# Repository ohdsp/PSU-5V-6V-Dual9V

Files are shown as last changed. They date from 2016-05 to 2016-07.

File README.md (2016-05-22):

# [Open Hardware DSP Platform](http://www.ohdsp.org)
## Multi output power supply for OHDSP
### Revision 1.1
###### PSU-5V-6V-Dual9V (KiCad 4.0.2-stable)
---
# README
### Disclaimer
Copyright Paul Janicki 2016

Licensed under the TAPR Open Hardware License (www.tapr.org/OHL)

This documentation is distributed WITHOUT ANY EXPRESS OR IMPLIED WARRANTY, INCLUDING OF MERCHANTABILITY, SATISFACTORY QUALITY AND FITNESS FOR A PARTICULAR PURPOSE.

### What is this repository? ###

**Quick summary**

This is a power supply for use with OHDSP boards.

This power supply requires a single 9Vac input (around 500mA should be sufficient for simple systems). 

This power supply outputs one 5V, one 5V or 6V, and +/-9V. Be warned that each of the 5V and 6V rail should be able to deliver higher currents (up to 1A) without issue, but this will overload the input if you are not careful.

This repository contains the KiCad design files, manufacturing Gerber/drill files, and PDF/drawing files for this board.

### How do I get set up? ###

**Summary of set up**

1. Set your self up a directory on a local disk, something simple will make life easier (eg C:\Electronics on Windows as used here), but anywhere will do just fine.
2. Download the Kicad-Libs from [https://github.com/ohdsp/KiCad-Libs](https://github.com/ohdsp/KiCad-Libs) and place in C:\Electronics\Kicad-Libs (or your chosen folder)  
3. Create a OHDSP subdirectory in C:\Electronics (so C:\Electronics\OHDSP)
3. Download this project to C:\Electronics\OHDSP\PSU-5V-6V-Dual9V
4. Fire up Kicad
5. Open the main project file C:\Electronics\OHDSP\PSU-5V-6V-Dual9V\Schematics\PSU-5V-6V-Dual9V.pro
6. (Optional) Setup Pcbnew component library as below.
7. Do as you wish with the project, just keep it under TAPR Open Hardware License

Make sure your git setup doesn't exclude files used in the project (like .LIB files) or things may go wrong down the line.

**KiCad Library Configuration**

Note that you need to setup a Pcbnew library, but the eeschema libraries should work without any changes if you followed the instructions above.

To setup Pcbnew libraries:

In Pcbnew go to Preferences -> Footprint Libraries Manager. Under Global Libraries tab in the top list check if there is a nickname "MyKiCadLibs-Footprints" (usually at the end of the list). If there is but it points to the wrong place then change the Library Path to point to MyKiCadLibs-Footprints (eg C:\Electronics\KiCad-Libs\MyKiCadLibs-Footprints.pretty) folder for your setup. If this is missing you can use "Append with Wizard", choose "Files on my computer", click next, browse to library location (eg C:\Electronics\KiCad-Libs\MyKiCadLibs-Footprints.pretty) and select the folder MyKiCadLibs-Footprints.pretty, click next, check the Status column states OK and the Format is KiCad (if not re-download the library) and click next, then select "To global library configuration..." and click Finish.

To setup eeschema component libraries:
Either from KiCad project window go to Tools -> Run Library Editor OR under eeschema, go to Tools -> Library Editor. Then Preferences -> Component Libraries.

The top section "Component Library Files" should ideally contain only two libraries, the "power" library that ships with KiCad and "MyKiCadLibs-Lib" available from above. To setup MyKiCadLibs-Lib as a relative path under the "User defined search path" click add. Browse to the location of KiCad-Libs you download above (eg C:\Electronics\KiCad-Libs) and click "Select Folder". Say yes to add a relative path. Under component library files click add, browse to the KiCad-libs again (eg C:\Electronics\KiCad-Libs), select file "MyKiCadLibs-Lib.lib" and click open. MyKiCadLibs-lib should appear in the component library list with no path as it will be using the user defined search path set in the box below.

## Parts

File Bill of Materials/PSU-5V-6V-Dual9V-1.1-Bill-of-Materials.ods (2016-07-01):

PSU-5V-6V-Dual9V Bill of Materials – Revision 1.1
20 May 2016
Reference | Quantity | Footprint | Value | Description | Voltage | Type | Tolerance | Size | Current | Power
C115 C116 | 2 | SMD-0805 | 100p | 'Ceramic capacitor | '50V | 'C0G | '5% | '0805 | ' | '
C105 C106 C117 C118 | 4 | CAP-TH-D18mmP7.5mm | 2200u | 'Aluminium electrolytic | '25V | ' | ' | '7.5mm Pitch, 18mm Diameter | ' | '
C103 C104 C109 C110 C119 C120 C129 C130 C133 C134 C141 C142 C145 C146 | 14 | SMD-0805 | 22u | 'Ceramic capacitor | '25V | 'X5R | '20% | '0805 | ' | '
C107 C108 C111 C112 C121 C122 C131 C132 C135 C136 C139 C140 C143 C144 | 14 | SMD-0805 | 100n | 'Ceramic capacitor | '50V | 'X7R | '10% | '0805 | ' | '
C113 C114 C123 C124 C125 C126 | 6 | SMD-0805 | 10n | 'Ceramic capacitor | '50V | 'X7R | '10% | '0805 | ' | '
C101 C102 C127 C128 C137 C138 C147 C148 C149 C150 | 10 | CAP-TH-D8mmP3.5mm | 220u | 'Aluminium electrolytic low impedance capacitor - eg Panasonic FC or FR parts | '25V | ' | ' | '3.5mm Pitch, 8mm Diameter | ' | '
D101 D102 | 2 | DIODE-SMC | ES3D | 'ES3D 3A 200V Fast Rectifier | ' | ' | ' | ' | ' | '
D103 D104 | 2 | DIODE-SMA | B240A | 'B240A 2A 40V Schottky Rectifier - SMA (DO-214AC) | ' | ' | ' | ' | ' | '
D105 D106 D107 D108 | 4 | DIODE-SOD-123 | SS14L | 'SS14L 1A 40V Schottky rectifier - Sub-SMA (SOD-123) | ' | ' | ' | ' | ' | '
D109 | 1 | SMD-1206 | Green LED 1206 | 'Green LED - SMD - Vf 1.8V to 2.2V | ' | ' | ' | '1206 | ' | '
FID1 FID2 FID3 FID4 | 4 | FID-1MM-3MM | MNT_HOLE | 'Fiducial | ' | ' | ' | ' | ' | '
L101 L102 | 2 | SMD-0805 | 600R@100MHz | 'Ferrite bead, current rating 2A or higher, 600R@100MHz | ' | ' | ' | '0805 | '=>2A | '
L103 L104 | 2 | IND-TYS5040-HS | TYS50406R8M-10 | 'Laird Technologies TYS5040 6.8uH Inductor - 2.5A Irms, 2.9A Isat, 0.043ohm, 21MHz | ' | ' | ' | ' | '2.5A | '
MNT1 MNT2 MNT3 MNT4 | 4 | MNT_HOLE_3.2mm | MNT_HOLE | 'Mounting hole | ' | ' | ' | ' | ' | '
P103 P106 P107 P108 P109 P110 P111 P112 P113 P114 P115 P116 P117 | 13 | CONN-2WAY-2.54mm-3.81mm-SPACING | CONN_2x1 | '2 way screw terminal, any 2.54mm to 3.81mm pitch part | ' | ' | ' | ' | ' | '
R101 R103 | 2 | SMD-0805 | 475k | 'Thick or thin film resistor | ' | ' | '1% | '0805 | ' | '100mW
R102 R104 | 2 | SMD-0805 | 100k | 'Thick or thin film resistor | ' | ' | '1% | '0805 | ' | '100mW
R105 R106 | 2 | SMD-0805 | 47 | 'Thick or thin film resistor | ' | ' | '1% | '0805 | ' | '100mW
R107 | 1 | SMD-0805 | 53k6 | 'Thick or thin film resistor | ' | ' | '1% | '0805 | ' | '100mW
R108 R111 | 2 | SMD-0805 | 10k | 'Thick or thin film resistor | ' | ' | '1% | '0805 | ' | '100mW
R109 | 1 | SMD-0805 | 470 | 'Thick or thin film resistor | ' | ' | '1% | '0805 | ' | '100mW
R110 | 1 | SMD-0805 | 66k5 | 'Thick or thin film resistor | ' | ' | '1% | '0805 | ' | '100mW
R113 R114 | 2 | SMD-0805 | 750 | 'Thick or thin film resistor - 250mW | ' | ' | '1% | '0805 | ' | '250mW
R115 R116 | 2 | SMD-0805 | 120 | 'Thick or thin film resistor - 250mW | ' | ' | '1% | '0805 | ' | '250mW
U101 U102 | 2 | IC-SOT23-6 | ADP2301AUJZ | '1.2 A, 20 V, 700 kHz/1.4 MHz, Nonsynchronous Step-Down Regulator | ' | ' | ' | ' | ' | '
U103 | 1 | IC-TO220-HS-SW25-2G | LM317 | 'LM317 TO220 3-Terminal Adjustable Positive Regulator | ' | ' | ' | ' | ' | '
U104 | 1 | IC-TO220-HS-SW25-2G | LM337 | 'LM337 TO220 3-Terminal Adjustable Negative Regulator | ' | ' | ' | ' | ' | '

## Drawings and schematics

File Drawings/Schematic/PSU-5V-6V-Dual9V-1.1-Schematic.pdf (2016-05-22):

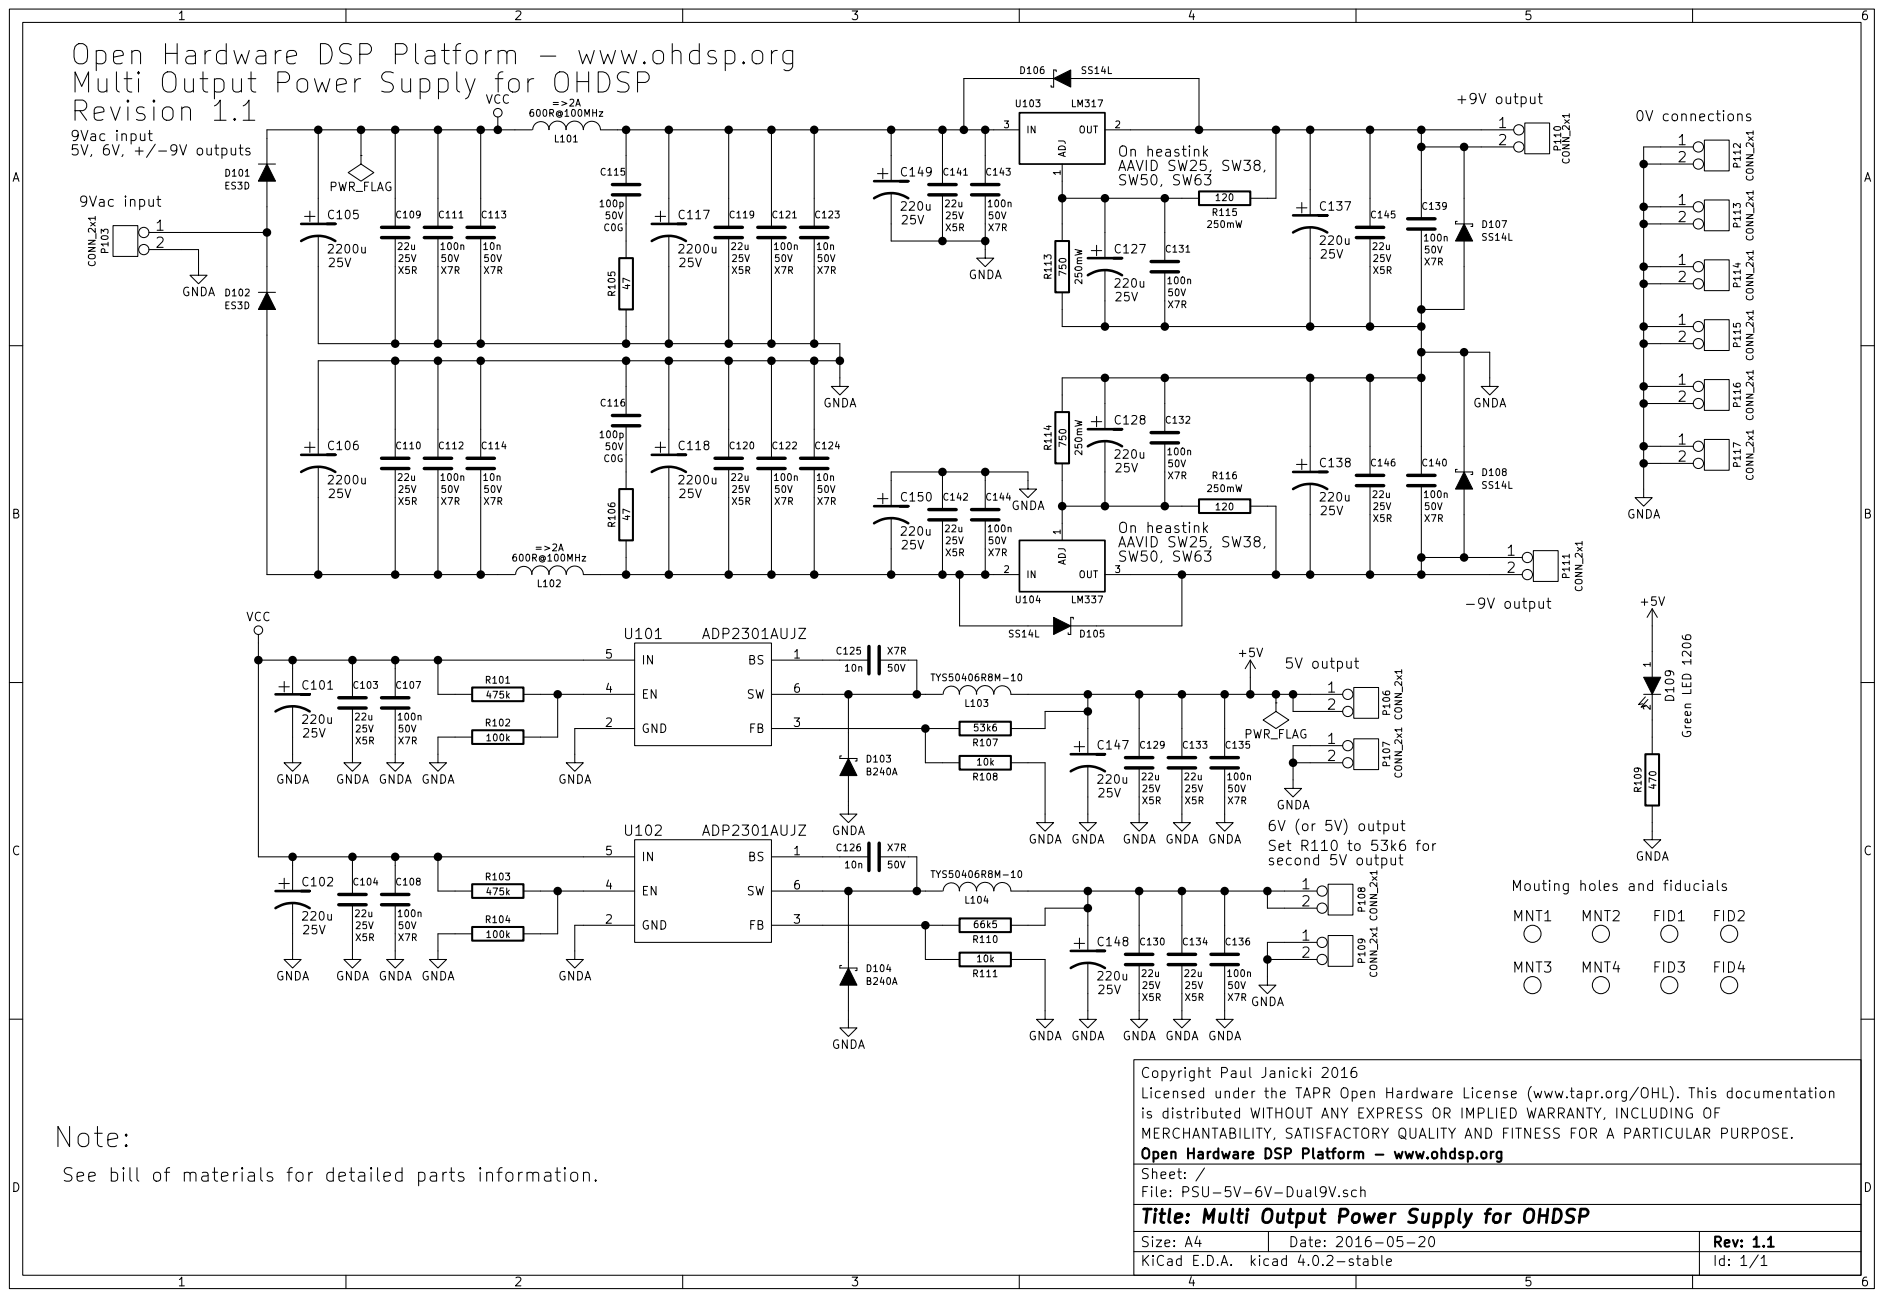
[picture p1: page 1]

Open Hardware DSP Platform - www.ohdsp.org
Multi Output Power Supply for OHDSP
Revision 1.1

Copyright Paul Janicki 2016
Licensed under the TAPR Open Hardware License (www.tapr.org/OHL). This documentation
is distributed WITHOUT ANY EXPRESS OR IMPLIED WARRANTY, INCLUDING OF
MERCHANTABILITY, SATISFACTORY QUALITY AND FITNESS FOR A PARTICULAR PURPOSE.
File: PSU-5V-6V-Dual9V.sch Sheet: / Open Hardware DSP Platform - www.ohdsp.org

Id: 1/1 Title: Multi Output Power Supply for OHDSP

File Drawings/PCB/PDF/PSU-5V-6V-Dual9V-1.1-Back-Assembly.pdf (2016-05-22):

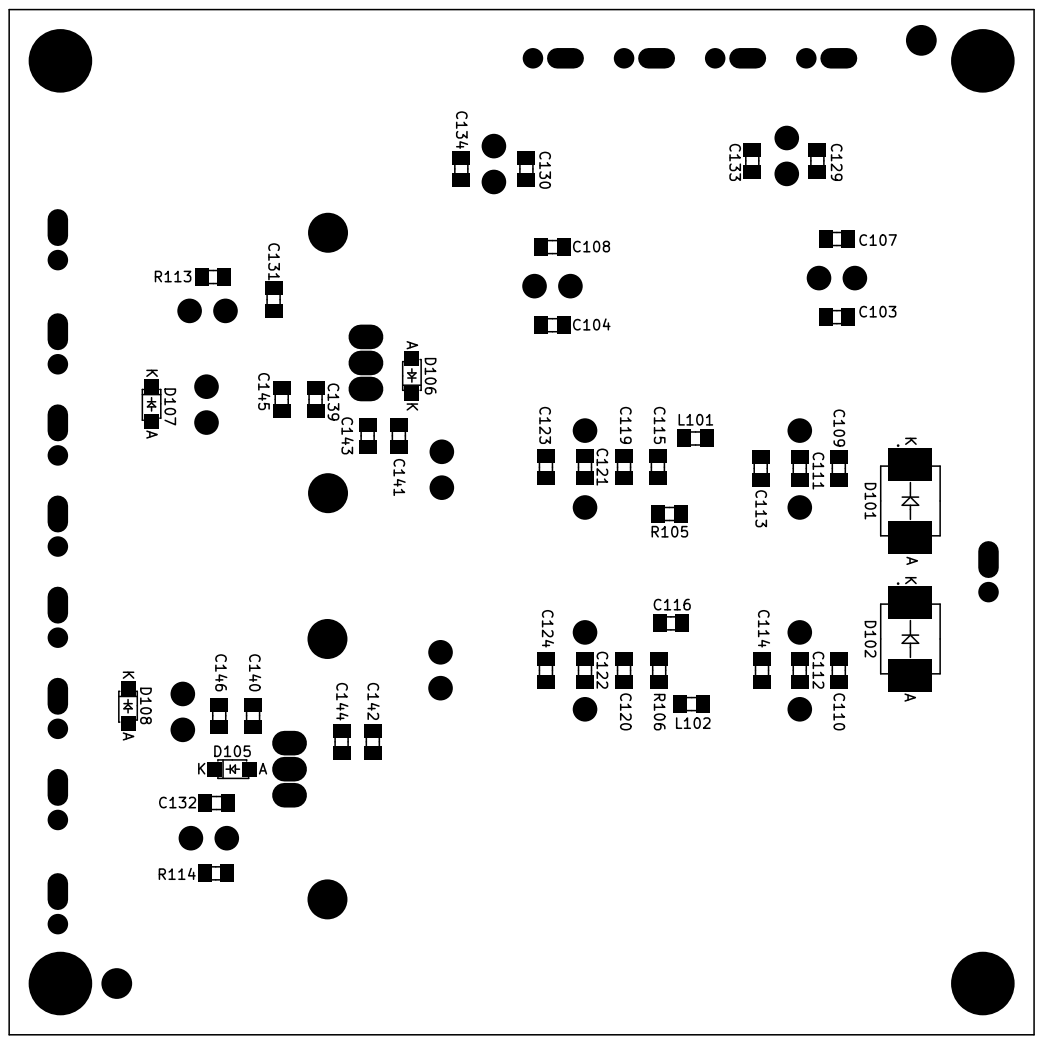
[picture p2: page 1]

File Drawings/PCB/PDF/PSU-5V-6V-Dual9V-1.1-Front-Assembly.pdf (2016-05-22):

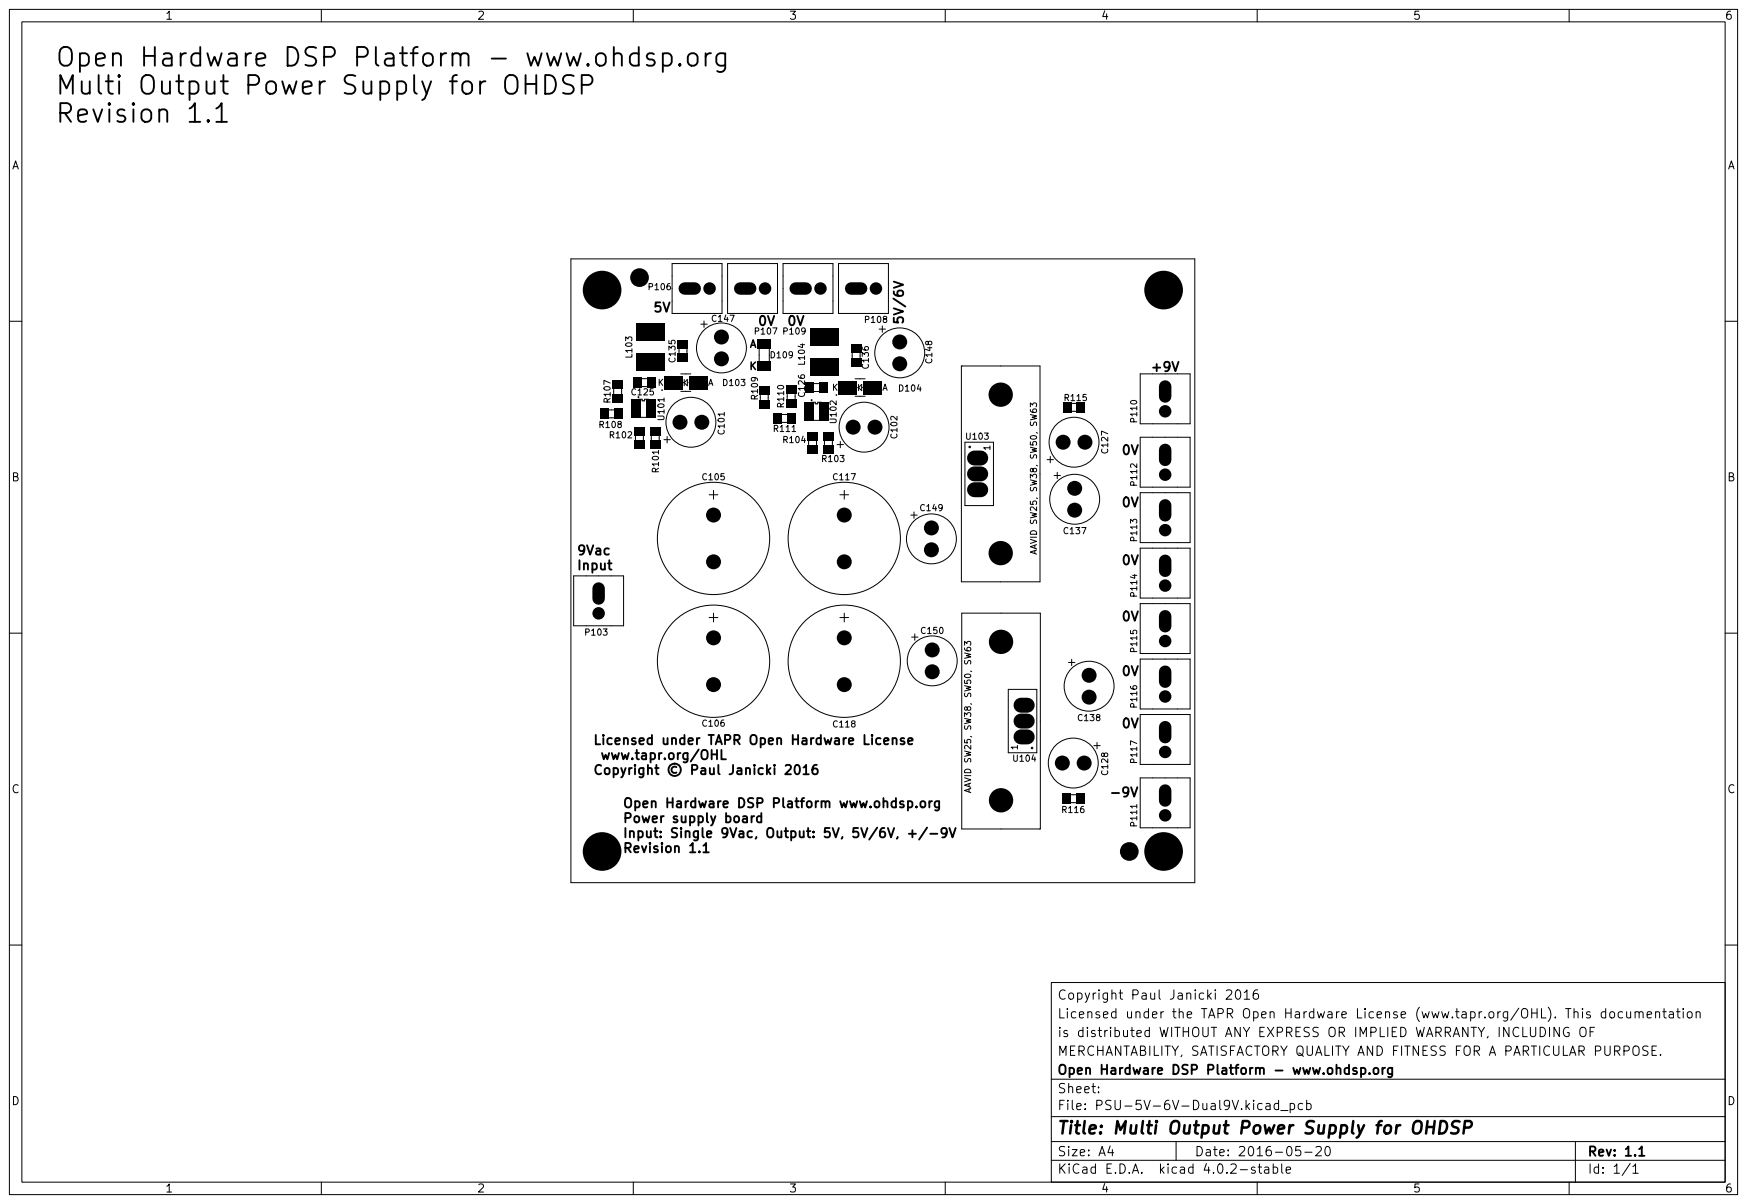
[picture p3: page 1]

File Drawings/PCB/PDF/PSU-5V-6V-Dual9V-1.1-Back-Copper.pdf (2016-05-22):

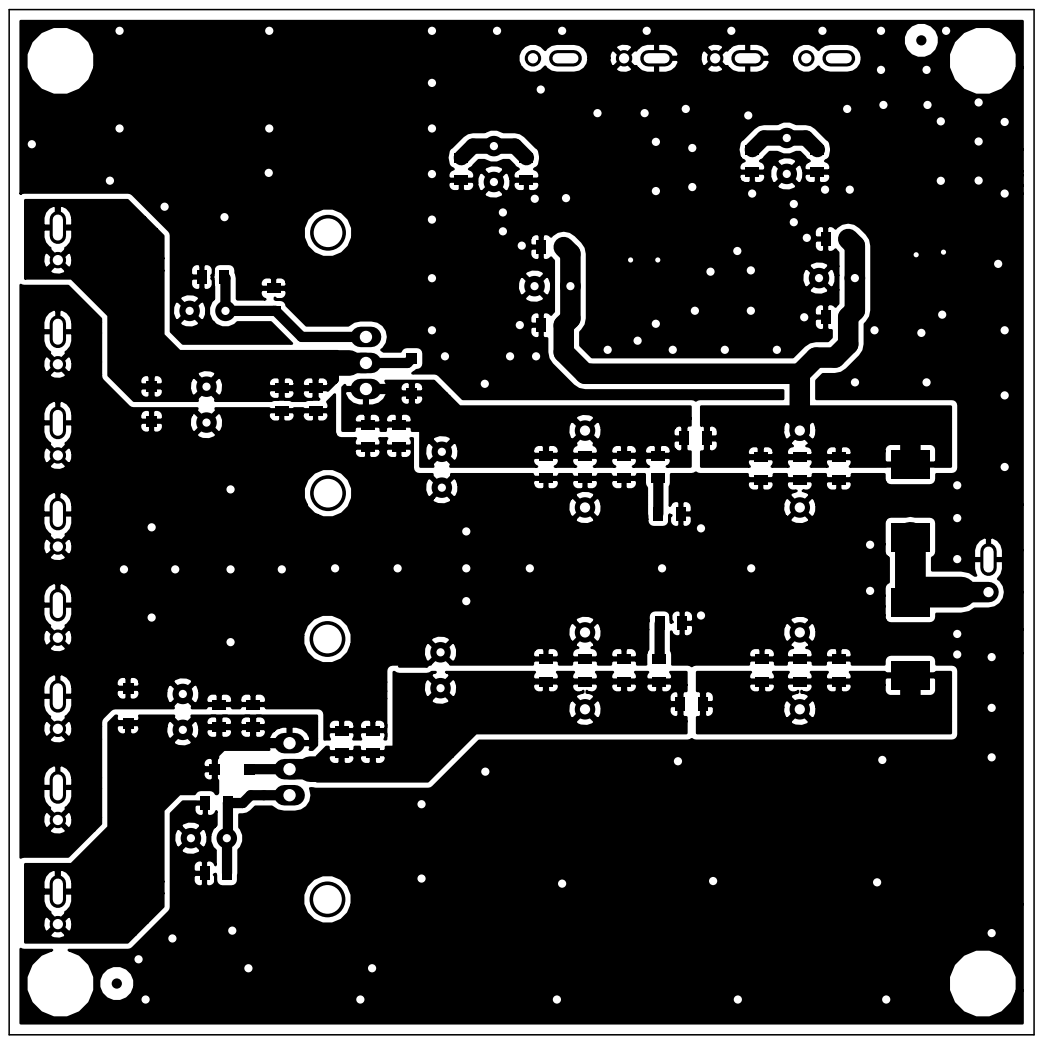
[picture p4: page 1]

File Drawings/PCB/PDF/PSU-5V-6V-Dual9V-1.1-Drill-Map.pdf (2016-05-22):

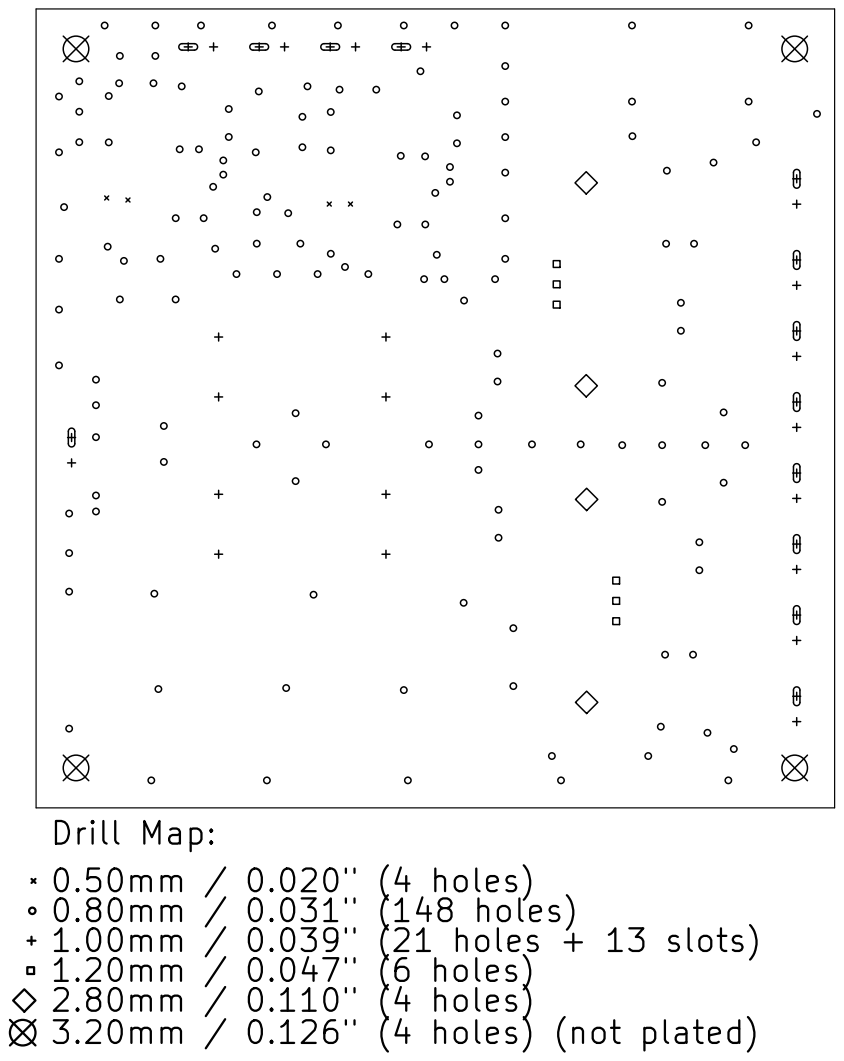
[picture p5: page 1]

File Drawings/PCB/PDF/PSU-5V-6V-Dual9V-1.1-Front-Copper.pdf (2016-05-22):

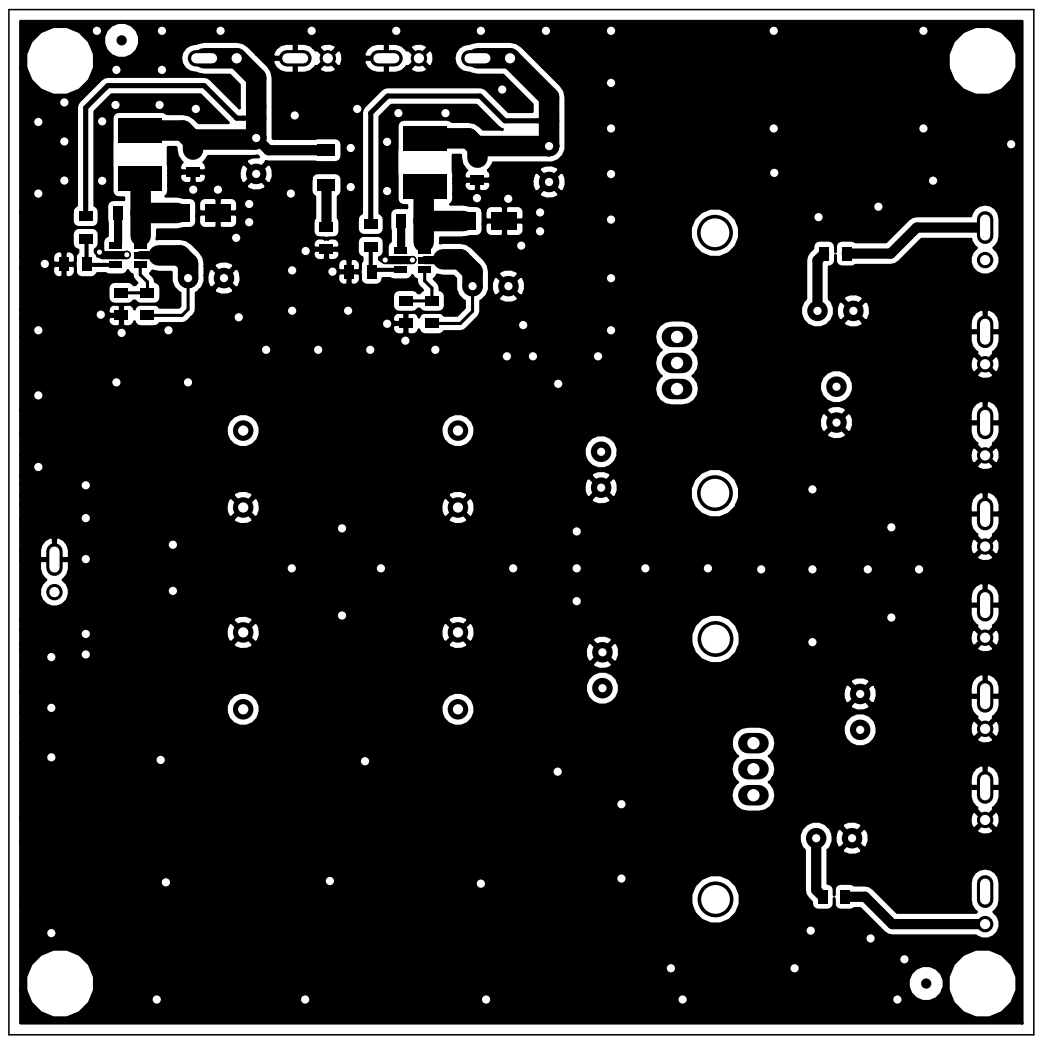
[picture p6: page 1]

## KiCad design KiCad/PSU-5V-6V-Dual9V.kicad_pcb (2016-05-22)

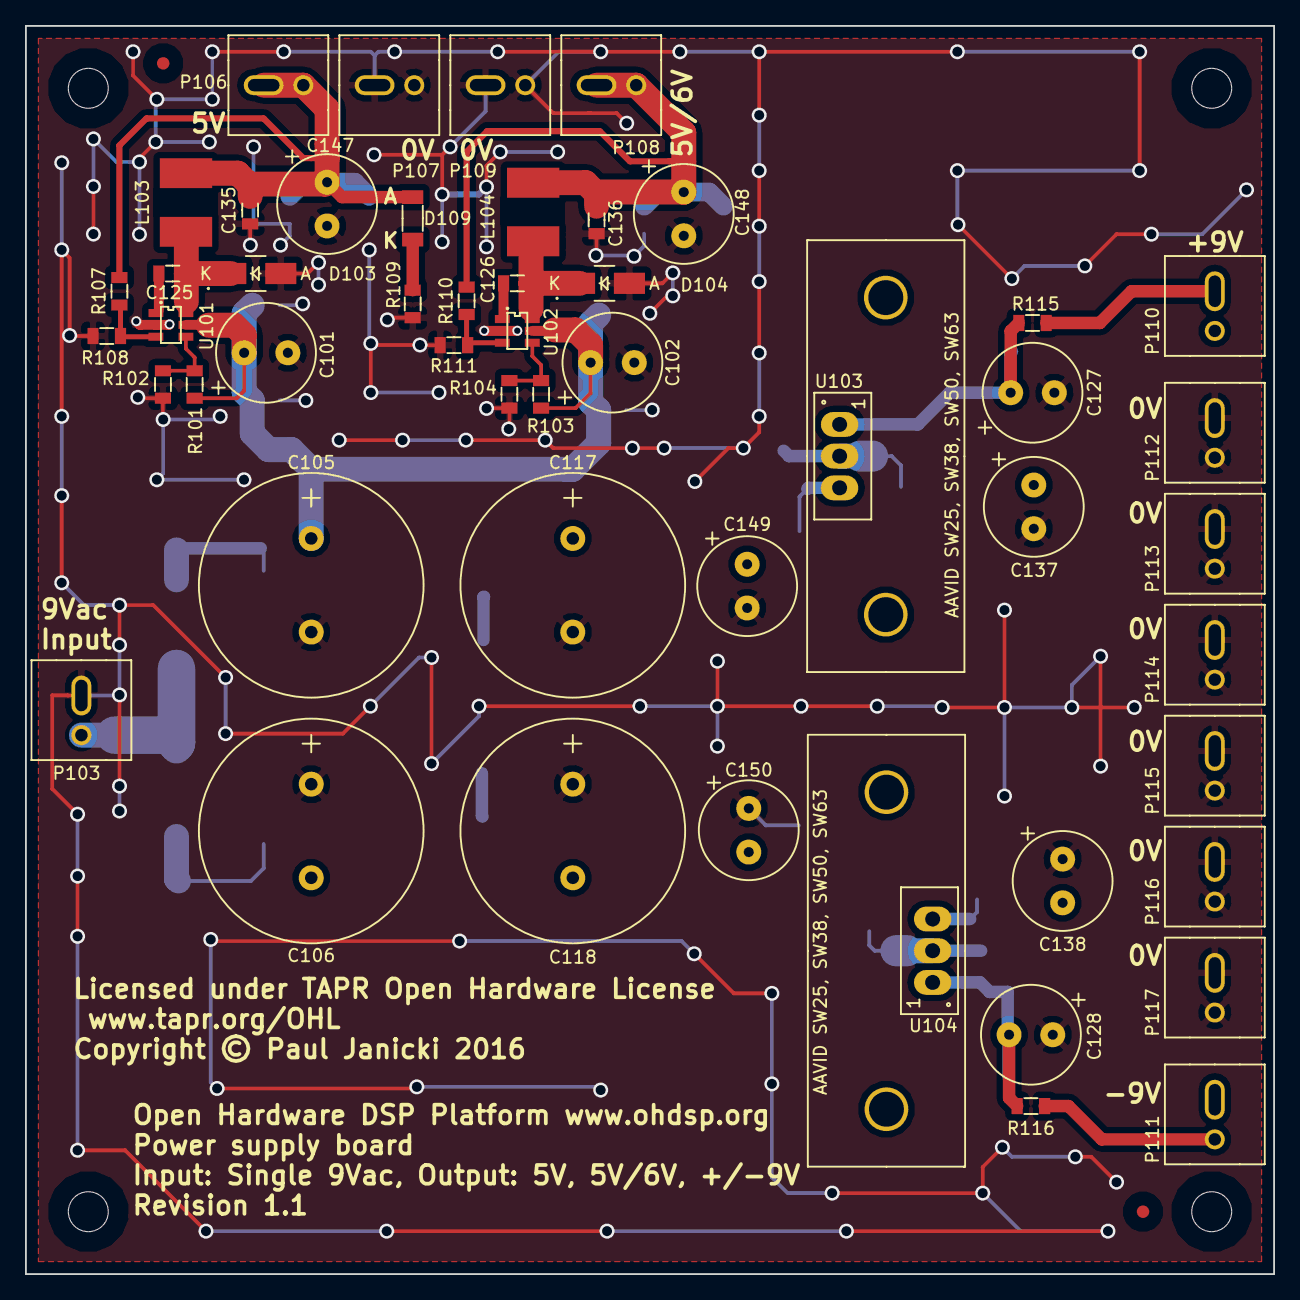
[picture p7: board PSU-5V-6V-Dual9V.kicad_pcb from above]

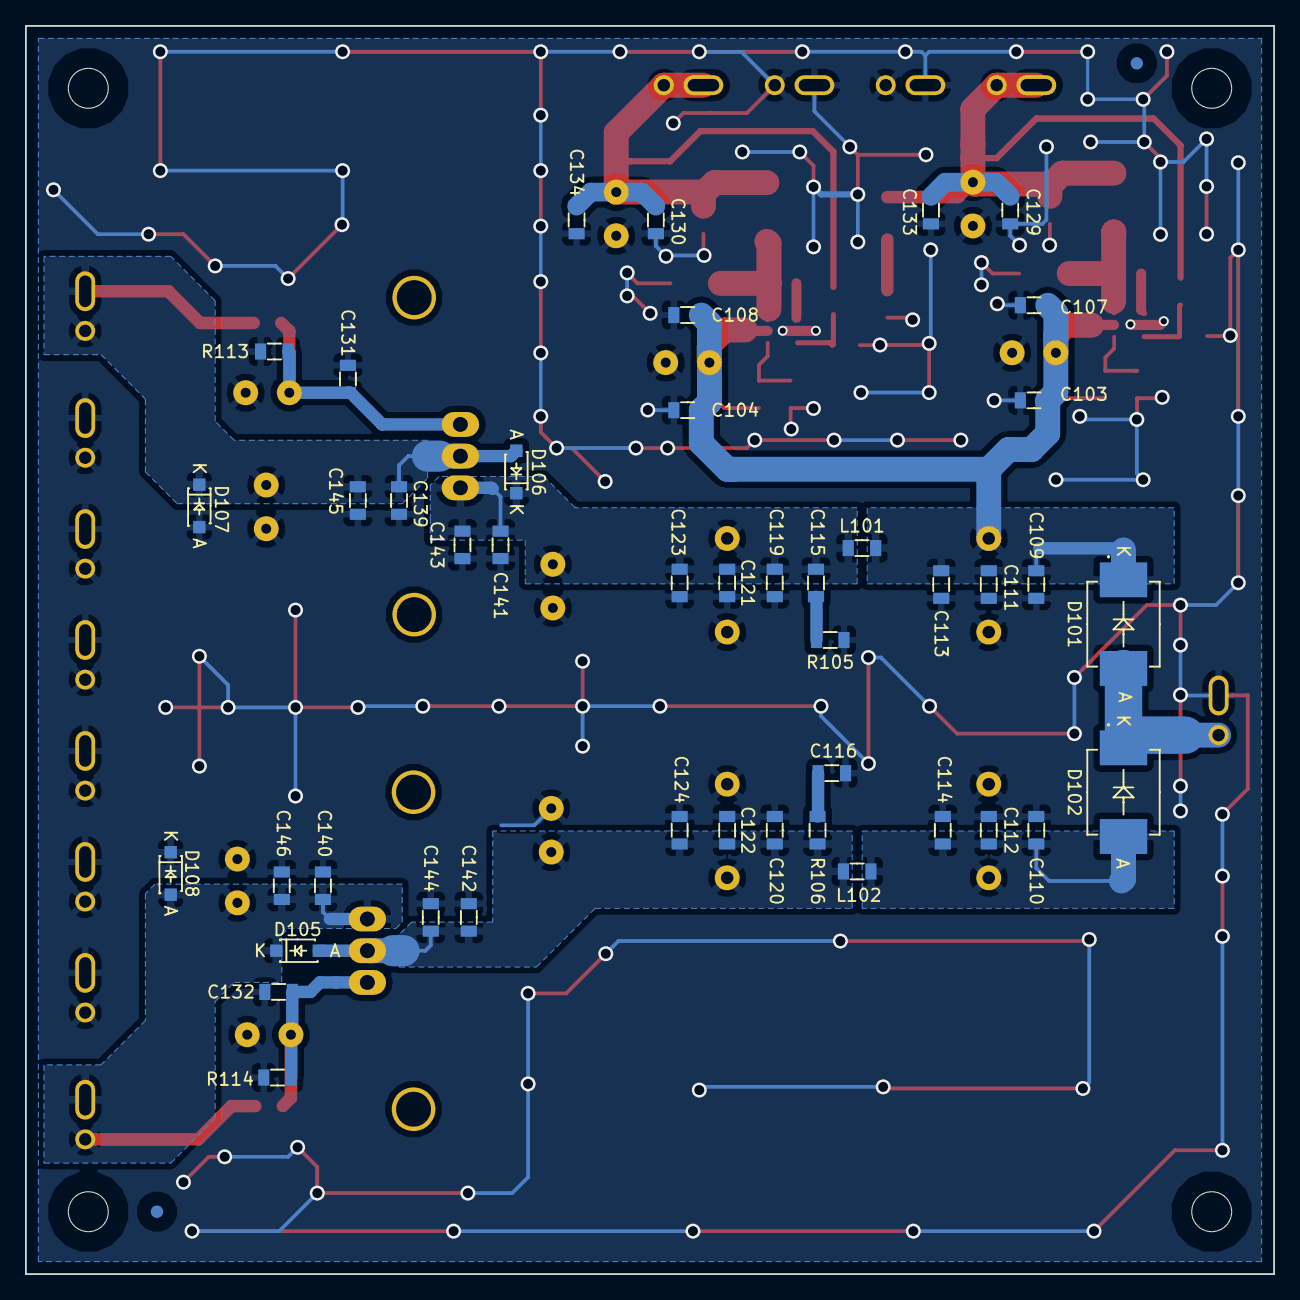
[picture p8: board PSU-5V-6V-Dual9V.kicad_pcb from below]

Board: 2 copper layers, 100.0 x 100.0 mm, 103 parts (46 on the bottom side), 23 nets.

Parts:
C101, C102, C127, C128, C137, C138, C147, C148, C149, C150: 220u; CAP-TH-D8mmP3.5mm
C103, C104, C109, C110, C119, C120, C129, C130, C133, C134, C141, C142, C145, C146: 22u; SMD-0805
C105, C106, C117, C118: 2200u; CAP-TH-D18mmP7.5mm
C107, C108, C111, C112, C121, C122, C131, C132, C135, C136, C139, C140, C143, C144: 100n; SMD-0805
C113, C114, C123, C124, C125, C126: 10n; SMD-0805
C115, C116: 100p; SMD-0805
D101, D102: ES3D; DIODE-SMC
D103, D104: B240A; DIODE-SMA
D105, D106, D107, D108: SS14L; DIODE-SOD-123
D109: Green LED 1206; SMD-1206
FID1, FID2, FID3, FID4: MNT_HOLE; FID-1MM-3MM
L101, L102: 600R@100MHz; SMD-0805
L103, L104: TYS50406R8M-10; IND-TYS5040-HS
MNT1, MNT2, MNT3, MNT4: MNT_HOLE; MNT_HOLE_3.2mm
P103, P106, P107, P108, P109, P110, P111, P112, P113, P114, P115, P116, P117: CONN_2x1; CONN-2WAY-2.54mm-3.81mm-SPACING
R101, R103: 475k; SMD-0805
R102, R104: 100k; SMD-0805
R105, R106: 47; SMD-0805
R107: 53k6; SMD-0805
R108, R111: 10k; SMD-0805
R109: 470; SMD-0805
R110: 66k5; SMD-0805
R113, R114: 750; SMD-0805
R115, R116: 120; SMD-0805
U101, U102: ADP2301AUJZ; IC-SOT23-6
U103: LM317; IC-TO220-HS-SW25-2G
U104: LM337; IC-TO220-HS-SW25-2G

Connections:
+5V: C129.1, C133.1, C135.1, C147.1, D109.1, L103.2, P106.1, P106.2, R107.1
GNDA: C101.2, C102.2, C103.2, C104.2, C105.2, C106.1, C107.2, C108.2, C109.2, C110.1, C111.2, C112.1, C113.2, C114.1, C116.1, C117.2, C118.1, C119.2, C120.1, C121.2, C122.1, C123.2, C124.1, C127.2, C128.1, C129.2, C130.2, C131.2, C132.1, C133.2, C134.2, C135.2, C136.2, C137.2, C138.1, C139.2, C140.1, C141.2, C142.1, C143.2, C144.1, C145.2, C146.1, C147.2, C148.2, C149.2, C150.1, D103.1, D104.1, D107.1, D108.2, P103.2, P107.1, P107.2, P109.1, P109.2, P112.1, P112.2, P113.1, P113.2, P114.1, P114.2, P115.1, P115.2, P116.1, P116.2, P117.1, P117.2, R102.2, R104.2, R105.2, R108.1, R109.1, R111.1, R113.1, R114.2, U101.2, U102.2
unnamed: C106.2, C110.2, C112.2, C114.2, D102.1, L102.1
unnamed: C115.1, C117.1, C119.1, C121.1, C123.1, C141.1, C143.1, C149.1, D106.2, L101.2, U103.3
unnamed: C115.2, R105.1
unnamed: C116.2, R106.1
unnamed: C118.2, C120.2, C122.2, C124.2, C142.2, C144.2, C150.2, D105.1, L102.2, R106.2, U104.2
unnamed: C125.1, D103.2, L103.1, U101.6
unnamed: C125.2, U101.1
unnamed: C126.1, D104.2, L104.1, U102.6
unnamed: C126.2, U102.1
unnamed: C127.1, C131.1, R113.2, R115.1, U103.1
unnamed: C128.2, C132.2, R114.1, R116.1, U104.1
unnamed: C130.1, C134.1, C136.1, C148.1, L104.2, P108.1, P108.2, R110.1
unnamed: C137.1, C139.1, C145.1, D106.1, D107.2, P110.1, P110.2, R115.2, U103.2
unnamed: C138.2, C140.2, C146.2, D105.2, D108.1, P111.1, P111.2, R116.2, U104.3
unnamed: D101.1, D102.2, P103.1
unnamed: D109.2, R109.2
unnamed: R101.1, R102.1, U101.4
unnamed: R103.1, R104.1, U102.4
unnamed: R107.2, R108.2, U101.3
unnamed: R110.2, R111.2, U102.3
VCC: C101.1, C102.1, C103.1, C104.1, C105.1, C107.1, C108.1, C109.1, C111.1, C113.1, D101.2, L101.1, R101.2, R103.2, U101.5, U102.5

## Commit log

2016-01-24 Release 1.0
    Release 1.0
    [PSU-5V-6V-Dual9V-Bill-of-Materials-1.0.csv, PSU-5V-6V-Dual9V-Bill-of-Materials-1.0.ods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]
2016-05-22 Revision 1.1
    [ADAU1452 PSU.sch, PSU-5V-6V-Dual9V-1.1-Bill-of-Materials.csv, PSU-5V-6V-Dual9V-1.1-Bill-of-Materials.ods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]
2016-07-01 Revision 2.0
    Update BOM sheet name
    [PSU-5V-6V-Dual9V-1.1-Bill-of-Materials.ods]
2016-07-01 Revert "Revision 2.0"
    This reverts commit c2e791a39c248d66cfa27da6c09bcea51845a439.
    [PSU-5V-6V-Dual9V-1.1-Bill-of-Materials.ods]
2016-07-01 Revision 1.1
    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
    [PSU-5V-6V-Dual9V-1.1-Bill-of-Materials.ods]

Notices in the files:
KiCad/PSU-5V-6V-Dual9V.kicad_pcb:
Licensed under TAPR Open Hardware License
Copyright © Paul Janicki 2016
